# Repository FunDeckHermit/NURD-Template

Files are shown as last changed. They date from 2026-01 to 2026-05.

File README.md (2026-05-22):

## NURDspace KiCAD template

This is a custom KiCAD symbol library and template for electronics design. It includes electronic parts grouped by type for easy use in circuit design, plus automated scripts for generating manufacturing artifacts.

## 📘 Overview

- **Total libraries:** 26
- **Total parts:** 1,614+
- **Format:** `.kicad_sym` (KiCAD 6+ compatible)
- **KiCAD Version:** 10.0+ (tested with KiCAD 8.0, 9.0, 10.0)
- **Template components:** 4 fiducial markers for PCB assembly

Each library holds parts like resistors, capacitors, diodes, and connectors. They are organised to make schematic design faster and more consistent.

---

## How to Use the Template

This template works with KiCAD's *Create a New Project from Template* feature. It sets up a ready-to-use schematic, PCB, and library configuration for new designs.

### Step 1 — Place the Template Folder

Copy the entire `NURD-template` folder into the KiCAD template directory. The location depends on your operating system and KiCAD version.

**Windows (KiCAD 10.0):**

```
C:\Users\<username>\Documents\KiCad\10.0\template\
```

**Windows (KiCAD 9.0):**

```
C:\Users\<username>\Documents\KiCad\9.0\template\
```

**Linux (KiCAD 10.0):**

```
/home/<username>/.local/share/kicad/10.0/template/
```

**Linux (KiCAD 9.0):**

```
/home/<username>/.local/share/kicad/9.0/template/
```

### Step 2 — Start KiCAD and Create a Project

1. Open KiCAD.
2. Go to **File → New Project → New Project from Template**.
3. Select **NURD-template** from the list.
4. Choose a folder and name for your new project.
5. KiCAD will copy all project files and libraries into the new folder.

### Step 3 — Start Designing

The new project will include:

- A schematic with linked libraries.
- A PCB layout with standard design rules.
- Configured symbol and footprint tables.
- 4 fiducial markers for automated PCB assembly (FID101-FID104).
- Folders for exports and Gerber outputs.

You can now start adding your own components and making changes.

---

## 🔧 Automated Artifact Generation

Two scripts are provided to automatically generate manufacturing artifacts from your KiCAD project.

### Linux/macOS: `generate_kicad_outputs.sh`

Generate all manufacturing and documentation artifacts in one command:

```bash
bash generate_kicad_outputs.sh [output_directory]
```

**Generates (12 outputs):**
- Schematic PDF
- PCB PDF (top & bottom layers)
- Top render (1400x1400 PNG)
- Bottom render (1400x1400 PNG)
- Isometric render (1400x1400 PNG)
- Drill files (Excellon format + PDF map)
- STEP 3D model
- Placement CSV (JLCPCB/PCBWay compatible)
- Bill of Materials CSV
- Gerbers ZIP (all layers + drill files, JLCPCB compatible)
- Build log
- Report

**Supported KiCAD versions:** 8.0, 9.0, 10.0

**Features:**
- Detects inner PCB layers automatically
- Splits large designator fields for JLCPCB compatibility (>2048 char limit)
- Generates interactive HTML BOM (if InteractiveHtmlBom is installed)
- Flatpak support
- Automatic error cleanup

### Windows: `generate_kicad_outputs_windows.bat`

Generate all manufacturing and documentation artifacts on Windows:

```batch
generate_kicad_outputs_windows.bat [output_directory]
```

**Generates (12 outputs):**
- Schematic PDF
- PCB PDF (top & bottom layers)
- Top render (1400x1400 PNG)
- Bottom render (1400x1400 PNG)
- Isometric render (1400x1400 PNG)
- Drill files (Excellon format + PDF map)
- STEP 3D model
- Placement CSV (JLCPCB/PCBWay compatible)
- Bill of Materials CSV
- Gerbers ZIP (all layers + drill files, JLCPCB compatible)
- Build log
- Report

**Supported KiCAD versions:** 8.0, 9.0, 10.0

**Auto-detection:**
- Searches for KiCAD CLI in standard installation paths
- Supports both 64-bit (Program Files) and 32-bit (Program Files x86) installations
- Automatically detects PCB layer configuration

**Usage example:**
```batch
cd path\to\your\project
.\generate_kicad_outputs_windows.bat
```

This creates a `kicad-artifacts` folder with all outputs.

### Output Details

#### Manufacturing Files
- **`*_gerbers.zip`** - Production-ready Gerber files + drill holes (JLCPCB/PCBWay format)
- **`*_placement.csv`** - Pick & place coordinates (JLCPCB compatible headers)
- **`*_bom.csv`** - Bill of Materials with designators, values, MPN, footprints, and quantities

#### Documentation
- **`*_schematic.pdf`** - Full electrical schematic
- **`*_pcb.pdf`** - PCB layer visualization
- **`*_render-top.png`** - Top-side board render
- **`*_render-bottom.png`** - Bottom-side board render
- **`*_render-iso.png`** - Isometric 3D view
- **`*_board.step`** - STEP format 3D model for CAD
- **`*_drill-map.pdf`** - Drill hole reference map
- **report.txt** - Generation summary with layer and settings info

---

## Notes

- The library names start with `.NRD_`.
- The _project library can be used for project-specific parts.
- Based on Roy's MIT licensed NURDspace Library.
- Fiducial markers are set to **exclude from BOM** but **include in position files** for automated assembly.
- For JLCPCB/PCBWay orders, use the `*_gerbers.zip`, `*_placement.csv`, and `*_bom.csv` files directly.

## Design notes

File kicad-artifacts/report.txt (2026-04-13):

KiCad Export Report
===================

Project: NURD-template
Run at: 2026-04-13 21:42:01
Duration: 15s
KiCad Type: Flatpak

Render settings:
  Quality: high
  Resolution: 1400x1400
  Isometric rotation: 315,0,45

Gerber layers:
  F.Cu,In1.Cu,In2.Cu,B.Cu,F.Mask,B.Mask,F.Paste,B.Paste,F.SilkS,B.SilkS,Edge.Cuts

Drill:
  Format: Excellon
  Map: PDF

Placement:
  Format: CSV
  Units: mm
  Side: both

Interactive BOM:
  Fields: Value, Footprint, MF, MPN
  Grouped by: Value, Footprint
  DNP filtering: Enabled (kicad_dnp field)
  Layout: left-right
  Layer view: Front

Generated files:
build.log
drill
ibom.html
NURD-template_board.step
NURD-template_bom.csv
NURD-template_gerbers.zip
NURD-template_pcb.pdf
NURD-template_placement.csv
NURD-template_render-bottom.png
NURD-template_render-iso.png
NURD-template_render-top.png
NURD-template_schematic.pdf

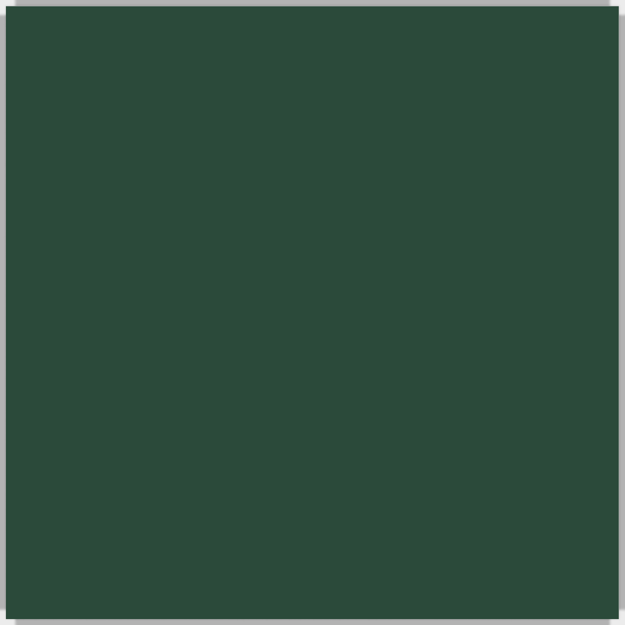
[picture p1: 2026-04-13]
kicad-artifacts/NURD-template_render-bottom.png

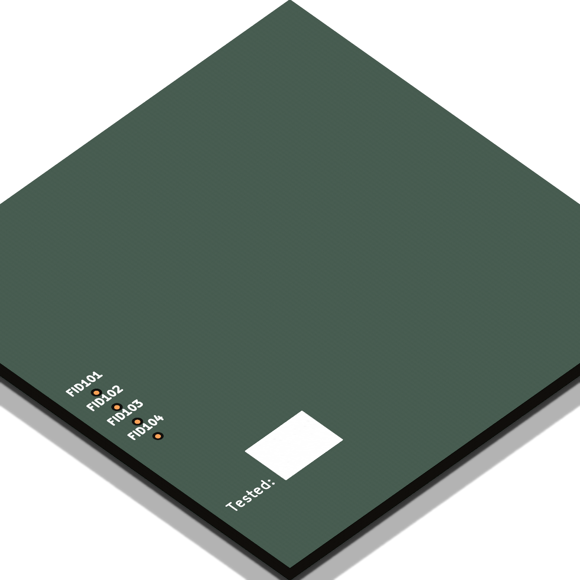
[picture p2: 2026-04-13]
kicad-artifacts/NURD-template_render-iso.png

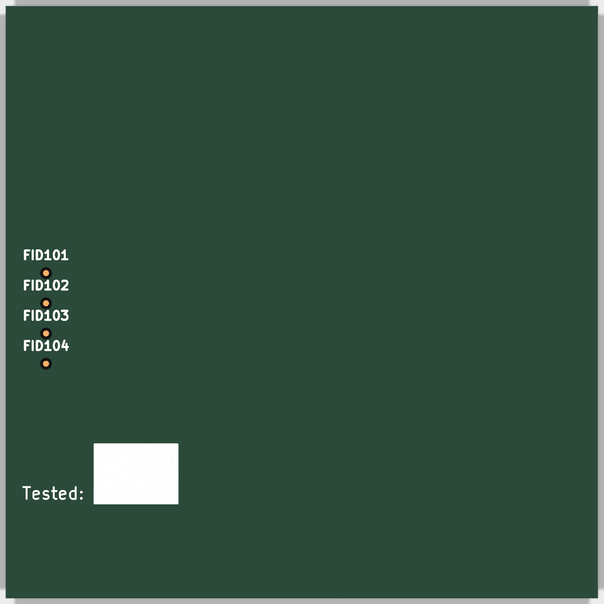
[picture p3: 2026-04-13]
kicad-artifacts/NURD-template_render-top.png

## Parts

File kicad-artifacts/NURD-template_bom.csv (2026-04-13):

Designator | Comment | MPN | Footprint | Quantity
U1 | MP2731 | MP2731GQC-0000-P | 0_NRD_footprints:MPS_QFN-26-35mmx35mm | 1

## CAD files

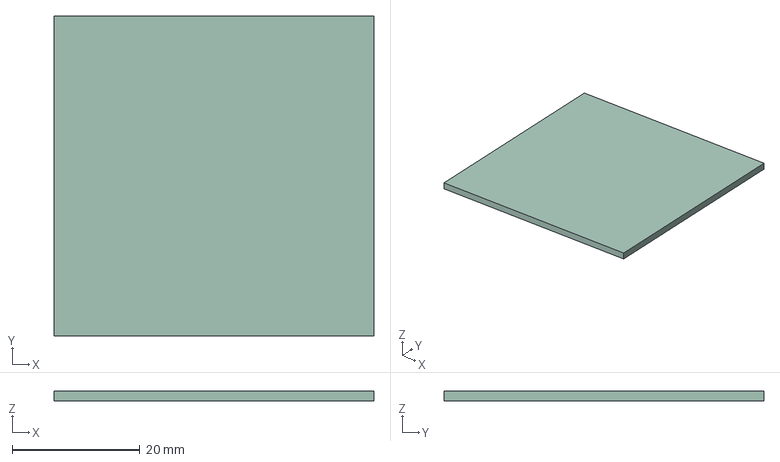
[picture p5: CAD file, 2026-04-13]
kicad-artifacts/NURD-template_board.step
50.0 x 50.0 x 1.50 mm

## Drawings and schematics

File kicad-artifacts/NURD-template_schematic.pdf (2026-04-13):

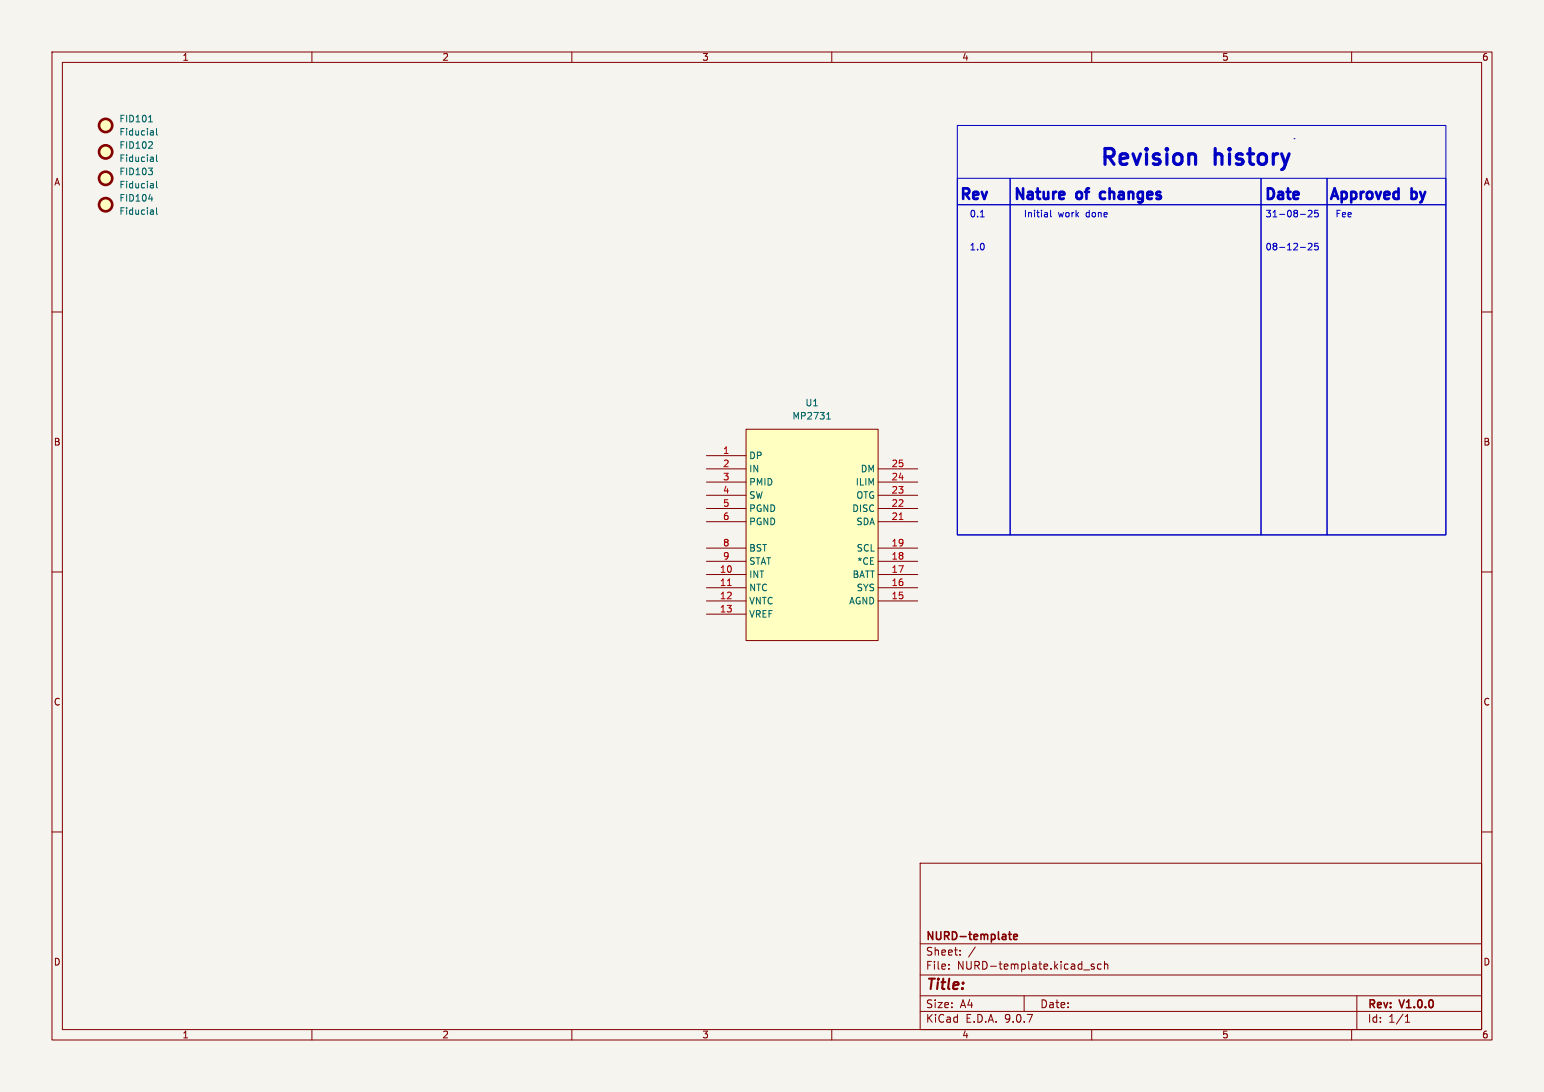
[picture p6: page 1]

Id: 1/1 Title: File: NURD-template.kicad_sch Sheet: / NURD-template

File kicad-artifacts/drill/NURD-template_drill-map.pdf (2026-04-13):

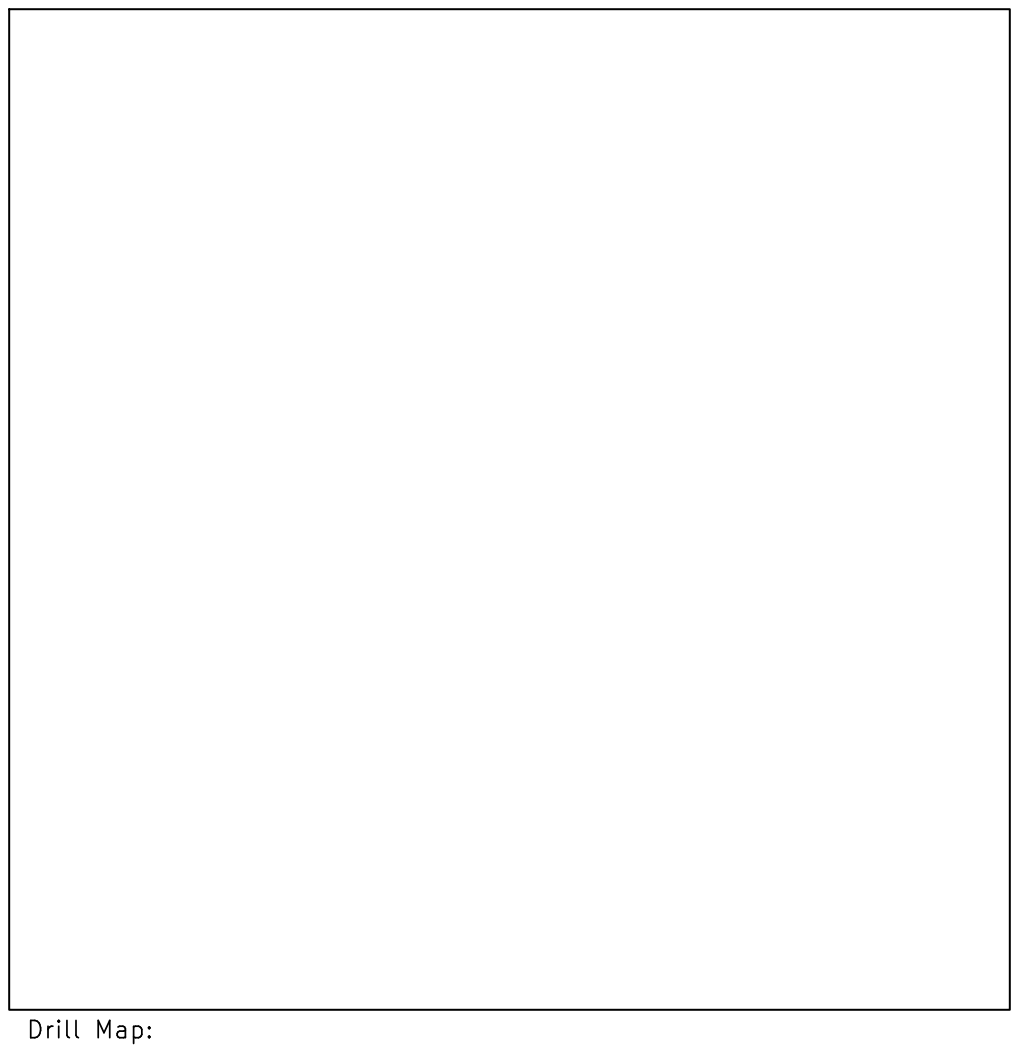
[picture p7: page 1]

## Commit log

2025-11-09 moved to sepererate dirs
    [026013144.stp, 0287001.PXCN.stp, 155060xx73200 (rev1).stp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]
2025-11-09 cut large files
2025-11-09 added description_full so KiCAD wont crash
2025-11-09 moved footprints to .pretty folder for fp mapping
2025-11-09 fixed footprint linking by prepending PCM_
2025-11-09 gave up on project template
    [BOM.xls, NURD Template.kicad_pcb, NURD Template.kicad_sch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]
2026-01-05 Abandoned PCM route, template is easier
    [026013144.stp, 0287001.PXCN.stp, 155060xx73200 (rev1).stp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]
2026-01-23 Fixed footprint lib path + generate drill files
2026-01-27 Enhance KiCad output script with exclusions and fixes for JLCPCB
    Added options to exclude DNP components and fix oversized Designator fields for compatibility.
2026-02-02 Added TPS63070 footprint
2026-02-08 Added corrected TPS63070 footprint
2026-02-08 Fixed TPS63070 silkscreen
2026-03-31 Added relays
2026-04-02 Added connectors
2026-04-13 Added MP2731
    [NURD-template.kicad_sch]
2026-04-13 Also regenerated the artifacts
    [BOM.xls, NURD-template_board.step, NURD-template_bom.csv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]
2026-04-20 Added wurth button
2026-04-22 Updated to KiCAD 10
    [NURD-template.kicad_pcb, NURD-template.kicad_sch]
2026-05-21 Added Some more parts from pumpfix project
2026-05-21 Fix PCB PDF export for KiCad 10 compatibility
    Fixed the PCB PDF export command to use only available copper layers (F.Cu, B.Cu) instead of hardcoded layers that may not exist (In1.Cu, In2.Cu). This resolves the "Failed to create file" error when running the generate script with KiCad 10.
    The issue was that the script attempted to export layers that don't exist in 2-layer boards, causing the multipage export to fail. Now it only exports the copper layers that are actually present on the board.
2026-05-21 Complete rewrite: Remove multipage PDF logic and simplify KiCad 10 compatibility
    Completely refactored the script to work with KiCad 10:
    - Removed all multipage PDF export logic and MP_DIR setup
    - Simplified run_kicad_cmd() - now each export uses inline error checking
    - PCB PDF now exports directly to file with --layers F.Cu,B.Cu (required in KiCad 10)
    - Removed all "return" statements from top-level code
    - Added sleep delays for directory operations to ensure files are flushed
    - Uses explicit error checking instead of complex helper functions
2026-05-22 Update README for KiCAD 10, add artifact generation documentation, and document template contents
2026-05-22 Refactor KiCad export script for improved clarity
2026-05-22 Refactor KiCad export script for improved clarity 2
2026-05-28 Added Molex connectors and other parts
2026-05-29 Make layer detection dynamic - supports 2, 4, 6, 8, and 10-layer boards
2026-05-29 Add BOM deduplication: aggregate duplicate MPNs into single rows with space-separated designators
2026-05-29 Fix PowerShell escaping in BOM deduplication command
2026-05-29 Add missing features from .sh script while preserving working functionality: schematic/PCB PDFs, renders, STEP, drill maps, placement header fix, duration tracking
2026-05-29 Fix gerber zipping with proper directory handling and fallback to System.IO.Compression
2026-05-29 Fix gerber zipping with proper PowerShell file existence checks
2026-06-01 Added QFN44 microcontroller footprint
2026-09-17 Add BOM filter that intersects references with non-DNP placement
